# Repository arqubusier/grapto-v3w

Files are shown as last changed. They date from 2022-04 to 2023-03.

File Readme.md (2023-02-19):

# Prerequisites

## CAD Development

- Install Freecad
- Install KiCad
- Install Freecad KiCad StepUp plugin.
- install ergogen https://docs.ergogen.xyz/ (see below)
- Install https://github.com/perigoso/keyswitch-kicad-library.
  - Use the "Plugin and Content Manager" program of Kicad.
  - add the library path for Switch_Keyboard_Kailh 
  - Add value of the Kicad variable "KICAD6_3DMODEL_DIR" to secondary 3D folder location in KiCad StepUp
- Download the usb connector 3d model from https://www.molex.com/molex/part/partModels.jsp?&prodLevel=part&partNo=2169900001&channel=products
  to <repo>/grapto-v3w-pcb/216990-0001_stp/
  
### ergogen

$ npm i ergogen
installing globally causes permission errors depending on environment

You need to hack the footprints in gen_src/footprints into your local install of ergogen.

run ergogen (-d flag ouputs svg in addition to svg)

$ cd gen_src
$ ergogen -d config.yaml

Then copy kicad pcbs into the respective kicad project

## FW Development

  # src
  git clone git@github.com:arqubusier/zmk.git

  # packages
  sudo pacman -S git \
    autoconf \
    automake \
    ccache \
    dfu-util \
    libtool \
    make \
    gcc \
    ninja \
    cmake \

  pip install --user west

  # toolchains
  export ZSDK_VERSION=0.13.2
wget -q "https://github.com/zephyrproject-rtos/sdk-ng/releases/download/v${ZSDK_VERSION}/zephyr-toolchain-arm-${ZSDK_VERSION}-linux-x86_64-setup.run" && \
    sh "zephyr-toolchain-arm-${ZSDK_VERSION}-linux-x86_64-setup.run" --quiet -- -d ~/.local/zephyr-sdk-${ZSDK_VERSION} && \
    rm "zephyr-toolchain-arm-${ZSDK_VERSION}-linux-x86_64-setup.run"

  # west setup
  cd <zmk-repo>
  west init -l app/
  west update
  west zephyr-export
  pip install --user -r zephyr/scripts/requirements-base.txt

  yay -S nrf5x-command-line-tools
# FW Development

## Flashing

cd <zmk-repo>
cd app
west flash 
cd 
# FW Development

## Building

west build -p -b grapto_v3w

## Flashing

west flash

# Usage

## Pair on Arch Linux

Set report mode characteristic to report

$ sudo bluetoothctl
menu scan
clean
transport le
back
scan on
connect E9:9E:30:E3:E4:5B

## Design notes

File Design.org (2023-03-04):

* Soc

** nrf51xx
obsolete

** nrf52xx

https://infocenter.nordicsemi.com/index.jsp?topic=%2Fstruct_nrf52%2Fstruct%2Fnrf52.html

** Devboard

PCA10040 is an identifier for the devboard
*** Toolchain

*** Programmer

Segger jlink recommended

edu mini version ca 200 kr

Can use nrf52-dk to program external soc 300-400kr.
But do not need to buy separate devboard.

could use keyboard as devboard

**  bl653
** ACN52840
https://www.mouser.se/datasheet/2/871/aconno_02052021_ACN52840-2005184.pdf

*** External seconds oscillator reduces current

why?
https://github.com/joric/nrfmicro/wiki/Components#crystal
*** System design
VDD
VBUS
GND
USBP
USBN
swdio to header
swdclk to header
swo to header
keymatrix 5 row, 6 col
Bootloader config pin
Status led
reset button
FASTCHG enable
( built in 32.768 kHz XTAL (20-30 ppm) )

* BLE
** GAP
Generic access profile - how to access link layer

*** Advertisment

- Advertisement packets sent periodically

To save battery while feeling responsive, the device can start with a short
interval and decrease if there is no connection.

**** Advertisement properties
- Connectable
- scannable
- directed

**** Advertisement types

| Packet           | Connectable | Scannable | Directed | Example device                                               |
|------------------+-------------+-----------+----------+--------------------------------------------------------------|
| ADV_IND          | yes         | yes       | yes      |                      |
| ADV_DIRECT_IND   | yes         | no        | yes      | smart watch, keyboard, send to specific known central        |
| ADV_NON_CONN_IND | no          | no        | no       |                                                              |
| ADV_SCAN_ID      | no          | yes       | no       | simple sensor, use central can use send request to read data |
|                  |             |           |          |                                                              |

*** Scanning

Scanning is done periodically with a certain
- interval
- duration

Passive scanning

Active scanning

*** Connection

** GAP Roles
Keyboard will have the Peripheral role.

PC is the central?

peripheral does advertising

*** Connection

- Peripheral can only be connected to one central a time

  1. peripheral advertises
  2. Central responds on advertising channel
  3. Connection is formed

** GATT
access to data layer

Hierarchical table

Table of:
- Profile
  - Services
    - characteristics (single data point)

Peripheral is a GATT server, owns the table

*** Characteristics

Operations:
- command
- request
  - response
- notification
...

* PCB
** Rev 2
*** Testpoints
testpoints on critical mcu pin's to determine if reflow is good
- all vccs
- grounds
*** Status led
*** reset button
*** bootloader config pin
*** new power muxing
* Battery
** CR20xx
c == "lithium", r == "round", NNNN = diameter and height: 2032 means 20 mm high and 3.2 mm tall

cr2032
3 V 235 mAh

cr2025

thinner than cr2032 but smaller capacity 170 mAh.

** Battery holder

cannot find a "midmount battery holder"

Create own battery clips.

** LiPo
*** Posthuman Battery Store 303450
https://www.aliexpress.com/item/4001059965613.html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
Brand Name: ANLB
Type: Li-polymer
Set Type: Batteries Only
Model Number: 303450
Origin: Mainland China
Nominal Capacity: 600mAh
Bundle: Bundle 1
Certification: CE
Size: 50*34*3.0mm
Replacement Battery: Yes
Battery Number: 1pcs-2PCS
Charging Voltage: 3.7~4.2V

*** How far to discharge

Unclear, no datasheet on battey

3-3.6 V
https://lygte-info.dk/info/BatteryLowVoltage%20UK.html

* Power managament
https://circuitdigest.com/article/what-is-ldo-low-dropout-voltage-regulator-and-its-significance-in-battery-operated-devices

transient repsonse, rf sending
dropout voltage
** Detect and turn off at low battery

Use voltage divider and adc of controller, compare battery with voltage
divider. if adc is to low go into deep sleep. Wake up with reset button.

Use voltage regulator at 3.0V. Go to deep sleep when when at 3.0v.

*** Chip based soloution

https://electronics.stackexchange.com/questions/174781/low-battery-detection
https://www.mouser.se/datasheet/2/115/DIOD_S_A0002900337_1-2541999.pdf

MIC803 4.5 uA
MIC803-30D4VC3 vcc 3.3v vth 3
MIC803-29D4VC3 vcc 3.3 vth 2.93
https://www.mouser.se/datasheet/2/115/DIOD_S_A0002900337_1-2541999.pdf 

https://www.mouser.se/ProductDetail/621-AP9211SA-AN-HAC7
Has cutoff at 3.2, can be placed inline with battery

** Power profile
https://devzone.nordicsemi.com/power/w/opp/2/online-power-profiler-for-bluetooth-le

Dadv = 1/24
Dactive = 4/24
Dsleep = 19/24

Iavg = Dadv*Iadv+Dsleep*Isleep+DActive*Iactive = 1/24*100+19/24*30+4/24*700 uA =
150 uA

During advertising (not bonded) for rev1. But I am not able to pair. Also could not
cleanly cut trace so there is still 1M resistance in parallell with Am meter. So
values might be marginally larger. When not transmitting the average current is 2uA.

For 1 period, 100ms, average current ca 100us. Nrf power profiler shows 93 us so
not too far off.


** Keyboard scenarios
https://devzone.nordicsemi.com/power/w/opp/2/online-power-profiler-for-bluetooth-le

*** Not connected/Paired
50 ms interval
*** Reconnection (ADV_DIRECT_IND)

Read more here
file:///home/herman/Downloads/HOGP_SPEC_V10.pdf
20 h/day
{
  "chip": "2",
  "voltage": "3",
  "dcdc": "on",
  "lf_clock": "lfxo",
  "radio_tx": "0",
  "ble_type": "adv",
  "ble_int": "500",
  "tx_size": "0"
}
not sure if these settings are correct but this gives 21 uA

Configure long connection interval, but trigger reconnection/reduce interval
when pressing a button.

*** Connected, sending keypresses
1-4 hours at a time, a few times during the day.

go to reconnection mode after 20 min.

{
  "chip": "2",
  "voltage": "3",
  "dcdc": "on",
  "lf_clock": "lfxo",
  "radio_tx": "0",
  "ble_type": "con",
  "ble_int": "7.5",
  "tx_size": "6",
  "rx_size": "0",
  "phy": "1mbps",
  "slave_latency": "0",
  "central_ppm": "20",
  "peripheral_ppm": "20"
}

650uA

** Which Regulator type?

Optimize for reconnection mode 21uA, round up to 50uA

** LDO
https://www.eevblog.com/forum/projects/choosing-an-appropriate-ldo-for-low-power-device/
https://electronics.stackexchange.com/questions/275605/choosing-the-right-power-regulator-for-battery-powered-designs
https://devzone.nordicsemi.com/f/nordic-q-a/75124/is-this-robust-nrf52840-1-8v-low-power-mode-driving-rgb-led-from-3-3v

Is it better to use ldo than switchmode

Power approximation for LDO PD = (VIN – VOUT) × IOUT 
for battery (4.2-3.0)*I = 0.9*I when fully charged
nominally (3.7-3.0)*I = 0.5*I

for 50uA, PD = 25uW, n=.
P = 150uA*3V = 450 uW
for 150uA, PD = 75uW, n=450/(75+450)=0.85

lower quiescent current than spms.

fewer passives, smaller board space

THINK ABOUT THE DROPOUT VOLTAGE

transient response

*** TPS783xx
https://jlcpcb.com/partdetail/TexasInstruments-TPS78330DDCR/C118221

Iq 0.5uA

** Switchmode regulators

power approximation VIN = VOUT/Efficienccy = VOUT/0.9
Vregulator = Vout*(1/efficiency - 1) = Vout*(1/0.9 - 1) = Vout*0.11

for 50uA, 3.7V: VIN = 50*3.7*0.11 uW = 20uW

https://jlcpcb.com/partdetail/TexasInstruments-TPS63051RMWR/C139412
https://jlcpcb.com/partdetail/TexasInstruments-TPS63001DRCR/C28060

*** TPS62822
In stock at jlcpcb
https://jlcpcb.com/partdetail/TexasInstruments-TPS62822DLCR/C473385

see table on page 10
recommended output filter 0.47uH 22uF

r3, (PG) when not used can be left floating

*** TPS54331DR
To low minimum
input volgage
*** TPS6226x
For 1 cell lion batteries

small inductor 2.2 uH required
https://www.ti.com/cn/lit/ds/symlink/tps62260.pdf?ts=1677701886702&ref_url=https%253A%252F%252Fjlcpcb.com%252F

18 uA Iq
Rdson 150mOhm

*** TPS6242x
https://www.ti.com/cn/lit/ds/symlink/tps62420.pdf?ts=1677701846178&ref_url=https%253A%252F%252Fjlcpcb.com%252F

*** TPS6305x
** Battery disconnect switch (w7)
All smt slide switches I can find have I_max < 500 mA.
 - Use switch to turn off transistor that disconnects battery.
** Battery USB power muxing
*** None
- How is resistance of battery compared to mcu?
  will the battery "steal" all current?
  *Don't think this is an issue*
- Charging management is affected
  - More current will pass through the charger
  - Changing of states (CC, CV, etc.) might be negatively affected.
- System load will share current with battery from charger,
  charge current will be smaller. It may also vary due to system load.
- Charger turns off when charge current drops below threshlod. System load
  may cause charger to stay on when battery is 100% could lead to overcharge.
*** charger with power path
**** MCP738x
https://www.mouser.se/datasheet/2/268/20001984g-846362.pdf
- Not sure if battery in parallel with system ok.
**** BQ24073 WINNER!
https://www.mouser.se/ProductDetail/Texas-Instruments/BQ24073RGTR?qs=ZV%2Fxhq4oszqX%2F3rMt%2FwIsw%3D%3D
or BQ24072
- 1.5 A charge (wall adapter)
- input overvoltage
- Reverse current protection
- output short-circuit protection
- thermal protection
- reverse current protection
- inrush limit
- safety timers

***** Charging

- charge rate
- battery charge voltage 4.2, BQ24072, BQ24073, BQ24075, BQ24075
- charge rate I_charge set by ISET
- CHG on (low), means charging
- Flashing CHG, means error during charge
***** Current limit
During poweron, input current limit is first set to 100mA.
En1, EN2, R_ilim
***** Power management
- EN1 == EN2 == hi, in power ON, standby mode, battery power, input power disconnected
- Bq24073, out is regulated when IN present
  - DPPM Mode: if Vout starts dropping, charing current will be reduced
  - Battery Supplement mode: if charging current drops to zero and system load
    is greater than input current limit, OUT will not be regulated, but the
    battery will be connected directly to out
  - When no input source is present, battery is directly connected to out and no
    regulation is performed.
- Input current is current limited compliant with usb
- Input cap less than 10uF to limit inrush current
- Input current level controlled either by EN1/EN2 or resistor between ILIM an VSS.
***** Testing
Disconnect battery, connect charger.
1. OUT == ???

Connect battery, connect charger.
1. Input current is less than or equal to 100 mA.
2. CHG is on, PGOOD is on
3. Heat of ic is ok.
5. when charging is done CHG turns off
6. battery voltage is 4.2 V
***** Charging
max(current limit, I_chg)

I_chg = K_iset / R_iset

TD pin should be floating or low to enable charge termination.

TMR controls charge timers. Leave floating to use default values.

TS, battery pack temperature monitoring, connect 10 kOhm resistor from TS to VSS
to enable charging without temperature monitoring.

ILIM  Leaving ILIM unconnected disables all charging.

***** Thermal
Connect thermal pad to vss

thermal performance 
θ_JA = (T_J - T) / P 

P = [V(IN) – V(OUT)] × [I(OUT) + I(BAT)] + [V(OUT) – V(BAT)] × I(BAT)

eg.

P = [5.5 - 4.4]*0.500+[4.4-3.4]*0.500 W = 1.05 W

Test charging at 400 mA and see if battery or charger does not get too warm.

***** System design
BAT
!CE Connect to logic low to enable charging
!CHG Connect to led with resistor, indicates charging, flashes if error during charging
EN1 connect to logic low
EN2 connect to mcu, logic 1 FASTCHG enables 500mA current limit
ILIM Connect to resistor RILIM to ground = KILIM / RILIM
  RILIM = KILIM/ILIM ~ 1525/0.5 = 3.05 kOhm, Use 3.3 kOhm for smaller current
  limit
IN connect to VBUS, add cap less than 10uF to limit inrush current
ISET connecto to resistor RISET to grount = KISET/RISET
  RISET = KISET/ISET ~ 890/0.4 Ohm = 2.225 KOhm, use 2.2 kOhm resistor
ITERM leave unconnected for default termination current
OUT connect to system, 4.4 V or battery voltage
!PGOOD connect to led with resistor, indicates good power source
SYSOFF Connect Sysoff to logic low to enable battery output
TD Connect to ground to enable charger termination
thermal pad connect to ground
TMR leave unconnected for default timer values
TS Connect 10 KOhm resistor to ground (enable charging without batt temp sensor)
VSS connect to ground.

**** BQ25616
https://www.mouser.se/ProductDetail/Texas-Instruments/BQ25616JRTWT?qs=GBLSl2Akiruk9chMI62zkQ%3D%3D
- 9.5 uA standby
- High input voltage
- powerpath
- usb otg
- switched
- 3 A charge
**** BQ24081
https://www.mouser.se/ProductDetail/Texas-Instruments/BQ24081DRCTG4?qs=sjHPNSjTyn1tPpHjbn571g%3D%3D
- Batter in parallel with system
- Safety timer
- 1 A charge
**** BQ25606
https://www.mouser.se/ProductDetail/Texas-Instruments/BQ25606RGET?qs=5aG0NVq1C4yFkgOQCbyUyg%3D%3D
- powerpath
- usb otg
- switched
- 3 A charge
- 58 uA standby current
- inrush current limit
**** BQ24195
https://datasheet.lcsc.com/lcsc/1912112237_Texas-Instruments-BQ24195LRGER_C417486.pdf

*** diode oring

https://www.mouser.se/datasheet/2/916/PMEG3020CEP-1599881.pdf

If=1A,Tj=25 -> R<360mOhm

use beefier schottky on the usb side

*** IC powermux
TPS2110, TPS2111
https://www.ti.com/lit/ds/symlink/tps2110.pdf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
Around 100mOhm Rds(on)

+ more expensive than schottky
- lower on resistance
+ surge protection (could be useful for usb but might not be usable)
+ current limit -> no fuse for mcu needed
+ added IC dependency on component

*** Custom design

+ Cheap components?
+ lower on resistance than Schottky?
- complexity
- space
- Don't know how to limit cross-conductance

* Debug connector

Acn has a 6-pin connector. Pinout?????

* ESD
* Case

** w7

** w6

How much should the keyboard be raised? 7.5 mm at the end.

*** slanted case
- breaks w1

*** flip up feet
- breaks w2
- How to prevent slipping?

*** Tall bumpons at the back, sholt bumpons at the front

* Key pins

| logical name | bl653 pin | nrf52833 pin |
|--------------+-----------+--------------|
| col0         |        37 |            7 |
| col1         |        35 |            6 |
| col2         |        29 |            8 |
| col3         |        27 |           11 |
| col4         |        21 |           16 |
| col5         |        13 |           20 |
| row0         |        46 |           28 |
| row1         |        42 |            0 |
| row2         |        41 |            1 |
| row3         |        39 |            5 |
| row4         |         7 |           32 |

* flash map

- arduino boot loader
- soft device? NO zephyr uses it's own bluettooth stack
- application code 

* Troubleshooting
** Troubleshoot ZMK
*** Flash simple example
https://docs.zephyrproject.org/2.7.0/samples/basic/blinky/README.html
**** on nrf52dk in zephyr tree
https://docs.zephyrproject.org/latest/develop/getting_started/index.html

cd ~/bin
wget https://github.com/zephyrproject-rtos/sdk-ng/releases/download/v0.14.2/zephyr-sdk-0.14.2_linux-x86_64.tar.gz
wget -O - https://github.com/zephyrproject-rtos/sdk-ng/releases/download/v0.14.2/sha256.sum |shasum --check --ignore-missing
tar -xzvf zephyr-sdk-0.14.2_linux-x86_64.tar.gz
cd ~/src
mkdir zephyrproject2
cd zephyrproject2
west init
west update
west zephyr-export
cd ~/src/zephyrproject2/zephyr
pip install --user scripts/requirements.txt

***** blinky
cd ~/src/zephyrproject2/zephyr
west build -p auto -b nrf52dk_nrf52832 samples/basic/blinky
west flash

WORKS led is blinking

***** ble
west build -p auto -b nrf52dk_nrf52832 samples/bluetooth/peripheral_hids
west flash

Device shows up as Test HoG mouse in nrfConnect

**** on nrf52dk in zmk tree
**** on grapto in zephyr tree
works blinky and ble peripheral example works!

Added grapto_v3w board to zephyr 
https://github.com/arqubusier/zephyr/tree/grapto_v3w/boards/arm/grapto_v3w

**** on grapto in zmk tree

*** Try flashing zmk onto nrf52dk

soc is nrf52832_qfaa

not working
**** when building
FAILED: zephyr/zmk.elf zephyr/zmk.map zephyr/zmk.hex zephyr/zmk.bin zephyr/zmk.uf2 zephyr/zmk.lst zephyr/zmk.stat /home/herman/src/zmk/app/build/zephyr/zmk.map /home/herman/src/zmk/app/build/zephyr/zmk.hex /home/herman/src/zmk/app/build/zephyr/zmk.bin /home/herman/src/zmk/app/build/zephyr/zmk.uf2 /home/herman/src/zmk/app/build/zephyr/zmk.lst /home/herman/src/zmk/app/build/zephyr/zmk.stat 
: && ccache /home/herman/.local/zephyr-sdk-0.13.2/arm-zephyr-eabi/bin/arm-zephyr-eabi-gcc   zephyr/CMakeFiles/zephyr_final.dir/misc/empty_file.c.obj zephyr/CMakeFiles/zephyr_final.dir/dev_handles.c.obj zephyr/CMakeFiles/zephyr_final.dir/isr_tables.c.obj -o zephyr/zmk.elf  zephyr/CMakeFiles/offsets.dir/./arch/arm/core/offsets/offsets.c.obj  -fuse-ld=bfd  -Wl,-T  zephyr/linker.cmd  -Wl,-Map=/home/herman/src/zmk/app/build/zephyr/zephyr_final.map  -Wl,--whole-archive  app/libapp.a  zephyr/libzephyr.a  zephyr/arch/common/libarch__common.a  zephyr/arch/arch/arm/core/aarch32/libarch__arm__core__aarch32.a  zephyr/arch/arch/arm/core/aarch32/cortex_m/libarch__arm__core__aarch32__cortex_m.a  zephyr/arch/arch/arm/core/aarch32/mpu/libarch__arm__core__aarch32__mpu.a  zephyr/lib/libc/minimal/liblib__libc__minimal.a  zephyr/lib/posix/liblib__posix.a  zephyr/soc/arm/common/cortex_m/libsoc__arm__common__cortex_m.a  zephyr/soc/arm/nordic_nrf/nrf52/libsoc__arm__nordic_nrf__nrf52.a  zephyr/subsys/bluetooth/common/libsubsys__bluetooth__common.a  zephyr/subsys/bluetooth/host/libsubsys__bluetooth__host.a  zephyr/subsys/bluetooth/controller/libsubsys__bluetooth__controller.a  zephyr/subsys/net/libsubsys__net.a  zephyr/subsys/random/libsubsys__random.a  zephyr/drivers/adc/libdrivers__adc.a  zephyr/drivers/clock_control/libdrivers__clock_control.a  zephyr/drivers/gpio/libdrivers__gpio.a  zephyr/drivers/flash/libdrivers__flash.a  zephyr/drivers/entropy/libdrivers__entropy.a  zephyr/drivers/timer/libdrivers__timer.a  modules/hal_nordic/nrfx/libmodules__hal_nordic__nrfx.a  modules/drivers/kscan/libzmk__drivers__kscan.a  modules/drivers/sensor/battery/lib..__app__drivers__sensor__battery.a  -Wl,--no-whole-archive  zephyr/kernel/libkernel.a  -L"/home/herman/.local/zephyr-sdk-0.13.2/arm-zephyr-eabi/bin/../lib/gcc/arm-zephyr-eabi/10.3.0/thumb/v7e-m/nofp"  -L/home/herman/src/zmk/app/build/zephyr  -lgcc  -Wl,--print-memory-usage  zephyr/arch/common/libisr_tables.a  -no-pie  -mcpu=cortex-m4  -mthumb  -mabi=aapcs  -mfp16-format=ieee  -Wl,--gc-sections  -Wl,--build-id=none  -Wl,--sort-common=descending  -Wl,--sort-section=alignment  -Wl,-u,_OffsetAbsSyms  -Wl,-u,_ConfigAbsSyms  -nostdlib  -static  -Wl,-X  -Wl,-N  -Wl,--orphan-handling=warn && cd /home/herman/src/zmk/app/build/zephyr && /usr/bin/cmake -E rename zephyr_final.map zmk.map && /home/herman/.local/zephyr-sdk-0.13.2/arm-zephyr-eabi/bin/arm-zephyr-eabi-objcopy --gap-fill 0xff --output-target=ihex --remove-section=.comment --remove-section=COMMON --remove-section=.eh_frame zmk.elf zmk.hex && /home/herman/.local/zephyr-sdk-0.13.2/arm-zephyr-eabi/bin/arm-zephyr-eabi-objcopy --gap-fill 0xff --output-target=binary --remove-section=.comment --remove-section=COMMON --remove-section=.eh_frame zmk.elf zmk.bin && /usr/bin/python3.10 /home/herman/src/zmk/zephyr/scripts/uf2conv.py -c -f -b 0x0 -o zmk.uf2 zmk.bin && /home/herman/.local/zephyr-sdk-0.13.2/arm-zephyr-eabi/bin/arm-zephyr-eabi-objdump -d -S zmk.elf > zmk.lst && /home/herman/.local/zephyr-sdk-0.13.2/arm-zephyr-eabi/bin/arm-zephyr-eabi-readelf -e zmk.elf > zmk.stat
Memory region         Used Size  Region Size  %age Used
           FLASH:      146128 B       448 KB     31.85%
            SRAM:       42430 B        64 KB     64.74%
        IDT_LIST:          0 GB         2 KB      0.00%
usage: uf2conv.py [-h] [-b BASE] [-o FILE] [-d DEVICE_PATH] [-l] [-c] [-D]
                  [-f FAMILY] [-C]
                  [INPUT]
uf2conv.py: error: argument -f/--family: expected one argument
ninja: build stopped: subcommand failed.
FATAL ERROR: command exited with status 1: /usr/bin/cmake --build /home/herman/src/zmk/app/build
?1 ~/src/zmk/app % 

**** only build hex -> skip uf2conv.py
commented-out this line

#CONFIG_BUILD_OUTPUT_UF2=y

now I can build and flash

*** Start from working bl653 board in zmk

*** does not enter zmk's main

does not enter zmk's main.c
ends up in cpu_idle.s after z_arm_configure_static_mpu_regions

**** Need storage partition for bluetooth

**** Increase stack size

Added to Kconfig.defconfig

config MAIN_STACK_SIZE
    int
    default 4096

config SYSTEM_WORKQUEUE_STACK_SIZE
    int
    default 4096

config ISR_STACK_SIZE
    int
    default 4096

**** Check partition page alignment
page size is 4096

0x60000/4096 == 384 -> OK

total size is 512 KibiByte (I Assume, it sayes 512 KBytes on nrf homepage)
0x80000 == 524288
524288/1024 == 512 -> OK

**** Mpu config setting

Troubleshooting
***************

MPU fault while using NVS, or ``-ETIMEDOUT`` error returned
   NVS can use the internal flash of the SoC.  While the MPU is enabled,
   the flash driver requires MPU RWX access to flash memory, configured
   using :kconfig:`CONFIG_MPU_ALLOW_FLASH_WRITE`.  If this option is
   disabled, the NVS application will get an MPU fault if it references
   the internal SoC flash and it's the only thread running.  In a
   multi-threaded application, another thread might intercept the fault
   and the NVS API will return an ``-ETIMEDOUT`` error.

**** MPU error

void arm_core_mpu_configure_static_mpu_regions(const struct z_arm_mpu_partition
  static_regions[], const uint8_t regions_num,
  const uint32_t background_area_start, const uint32_t background_area_end)
{
  if (mpu_configure_static_mpu_regions(static_regions, regions_num,
                 background_area_start, background_area_end) == -EINVAL) {

    __ASSERT(0, "Configuring %u static MPU regions failed\n",
      regions_num);
  }
}

Hits assert!!!

**** partition@XXXXXXXX was wrong
&flash0 {
	/*
	 * Using no boot loader for now.
	 */
	partitions {
		compatible = "fixed-partitions";
		#address-cells = <1>;
		#size-cells = <1>;

		code_partition: partition@0 {
			label = "code_partition";
			reg = <0x00000000 0x60000>;
		};

		/*
		 * Storage partition will be used by FCB/LittleFS/NVS
		 * if enabled.
		 */
		storage_partition: partition@60000 { // PROBLEM WAS here
			label = "storage";
			reg = <0x00060000 0x00020000>;
		};
	};
};

*** hard fault
hard fault before main

static int zmk_usb_init(const struct device *_arg) {
zmk_endpoints_init(
static int zmk_usb_hid_init(const struct device *_arg)

zmk_battery_init

Skips main here
static void bg_thread_main(void *unused1, void *unused2, void *unused3)

** Right half not working

error when trying to program

ERROR: Unable to connect to a debugger.
ERROR: JLinkARM DLL reported an error. Try again. If error condition
ERROR: persists, run the same command again with argument --log, contact Nordic
ERROR: Semiconductor and provide the generated log.log file to them.
NOTE: For additional output, try running again with logging enabled (--log).
NOTE: Any generated log error messages will be displayed.
FATAL ERROR: command exited with status 33: nrfjprog --program /home/herman/src/zmk/app/build/zephyr/zmk.hex --sectoranduicrerase -f NRF52 --snr 682314080

*** Is mcu soldered on correctly?
Resolder

short on swdio to gnd!!!

*** Check swd connections on pcb
pwr 3v3 ok
*** monitor swd pins
*** Try program with usb power only
***

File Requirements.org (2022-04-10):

* Requirements
The project will go on indefinitely until these the system meets these.
| Id   | Description                                                                  |
|------+------------------------------------------------------------------------------|
| r1   | the keyboard is wireless                                                     |
| r2   | the keyboard is battery powered                                              |
| r3   | the keyboard has on-board charging                                           |
| r4.1 | the pcb protects the battery from overcharging                               |
| r4.2 | the pcb protects the battery from overdischarging                            |
| r4.3 | the pcb protects the battery from overcurrents                               |
| r4.4 | the pcb charges the battery in a manner that is safe given the its chemistry |
| r5   | the battery is charged using a usb cable                                     |
| r6   | the keyboard is split                                                        |
|      |                                                                              |

* Want to haves
I want the system to have these features.

| Id   | Description                                                                                |
|------+--------------------------------------------------------------------------------------------|
| w1   | The case is less than or equal to 6 mm in height                                           |
| w2   | The case only has a single seam on the bottom separating the top part from the bottom part |
| w3   | The keyboard can be operated with the usb plugged in and the battery unplugged             |
| w4   | Both halves can be charged using a single cable going to the usb charger                   |
| w5   | The keyboard can be operated with usb plugged in and the battery  plugged in               |
| w6   | the keyboard can be raised                                                                 |
| w6.1 | the keyboard raising mechanism does not need external parts                                |
| w7   | the battery can be disconnected using a switch                                             |
|      |                                                                                            |

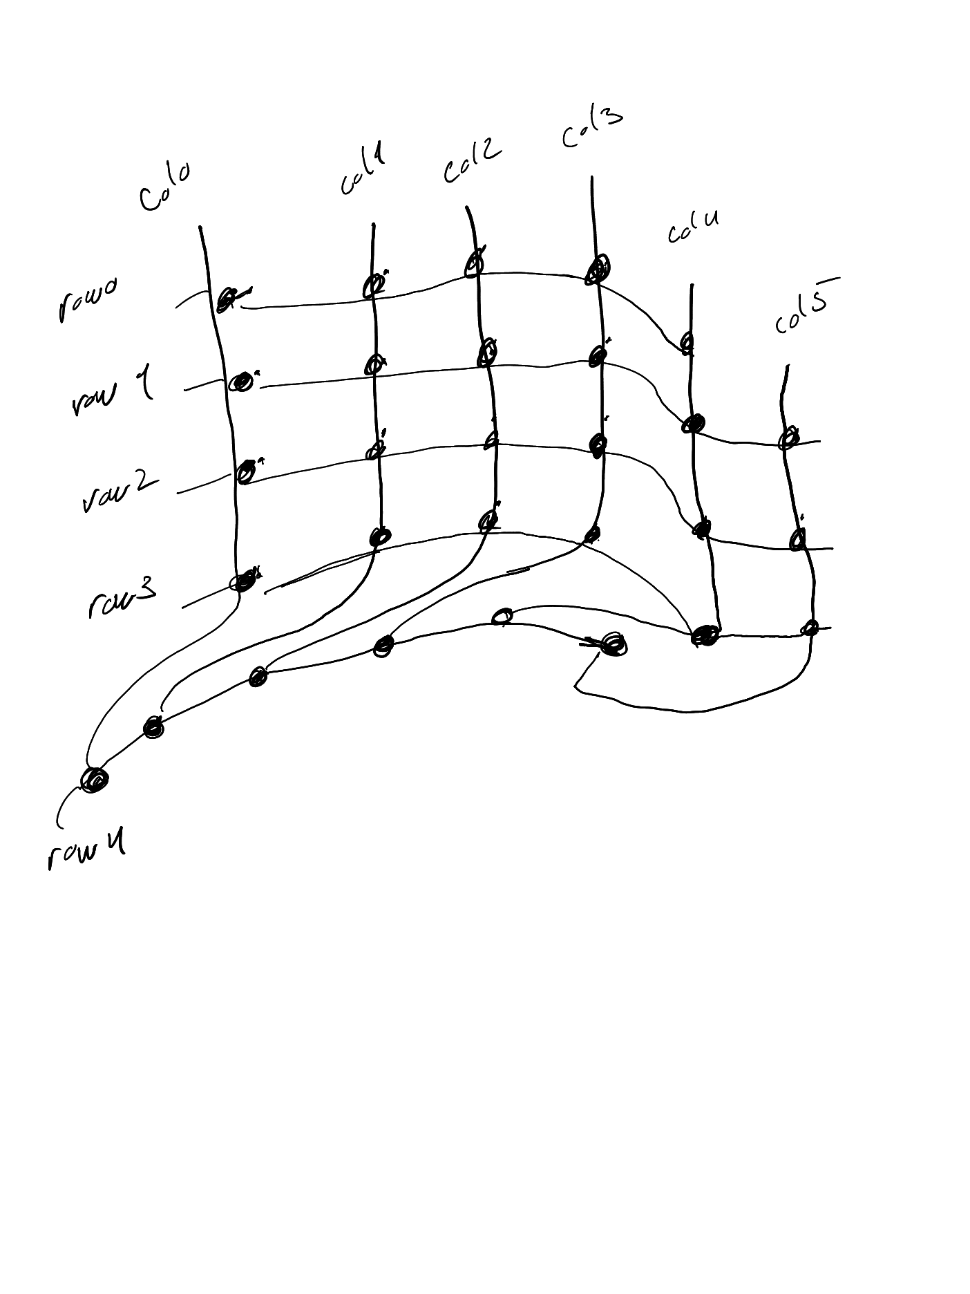
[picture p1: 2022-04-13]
grapto-v3w-shared/matrix.png

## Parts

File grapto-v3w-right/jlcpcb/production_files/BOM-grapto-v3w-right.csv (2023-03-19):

Comment | Designator | Footprint | LCSC
1M2 | R19 | R_0603_1608Metric_Pad0.98x0.95mm_HandSolder | C137774
.1u | C5 | C_0603_1608Metric_Pad1.08x0.95mm_HandSolder | C14663
1u | C1 | C_0603_1608Metric_Pad1.08x0.95mm_HandSolder | C15849
0.01m | R13,R14,R2 | R_0603_1608Metric_Pad0.98x0.95mm_HandSolder | C21189
3.3K | R7 | R_0603_1608Metric_Pad0.98x0.95mm_HandSolder | C22978
3M | R30 | R_0603_1608Metric_Pad0.98x0.95mm_HandSolder | C23156
5.1k | R20,R23 | R_0603_1608Metric_Pad0.98x0.95mm_HandSolder | C23186
22 | R24,R25 | R_0603_1608Metric_Pad0.98x0.95mm_HandSolder | C23345
100k | R9 | R_0603_1608Metric_Pad0.98x0.95mm_HandSolder | C25803
10K | R4 | R_0603_1608Metric_Pad0.98x0.95mm_HandSolder | C25804
453k | R5 | R_0603_1608Metric_Pad0.98x0.95mm_HandSolder | C273765
68 | R1 | R_0603_1608Metric_Pad0.98x0.95mm_HandSolder | C27592
LED_ARGB | D30,D31,D32 | 23-23B-R6GHBHC-A01-2A | C2827866
Polyfuse | F3,F4 | Fuse_0603_1608Metric_Pad1.05x0.95mm_HandSolder | C2844463
470n | L2 | MHCI05020-R47M-R8 | C285730
Conn_01x02_Female | J1 | JST_PH_S2B-PH-SM4-TB_1x02-1MP_P2.00mm_Horizontal | C295747
2.2K | R8 | R_0603_1608Metric_Pad0.98x0.95mm_HandSolder | C4190
TPS62822DLC | U2 | Texas_VSON-HR-8_1.5x2mm_P0.5mm | C473385
SW_SPDT | SW31 | SW_SK-3296S-01-L2 | C500051
 | S59,S60,S61,S62,S63,S64,S65,S66,S67,S68,S69,S70,S71,S72,S73,S74,S75,S76,S77,S78,S79,S80,S81,S82,S83,S84,S85,S86,S87 | PG1350 | C5333465
BQ24075RGT | U4 | VQFN-16-1EP_3x3mm_P0.5mm_EP1.6x1.6mm | C544783
22u | C10,C16,C17,C3,C4,C6,C7 | C_0603_1608Metric_Pad1.08x0.95mm_HandSolder | C59461
USBLC6-2SC6 | U3 | SOT-23-6 | C7519
 | D59,D60,D61,D62,D63,D64,D65,D66,D67,D68,D69,D70,D71,D72,D73,D74,D75,D76,D77,D78,D79,D80,D81,D82,D83,D84,D85,D86,D87 | ComboDiode | C81598
120p | C2 | C_0603_1608Metric_Pad1.08x0.95mm_HandSolder | C85974
~ | TP22 | TestPoint_THTPad_D2.0mm_Drill1.0mm
TestPoint | TP18 | TestPoint_THTPad_D2.0mm_Drill1.0mm
TestPoint | TP17 | TestPoint_THTPad_D2.0mm_Drill1.0mm
TestPoint | TP16 | TestPoint_THTPad_D2.0mm_Drill1.0mm
TestPoint | TP15 | TestPoint_THTPad_D2.0mm_Drill1.0mm
TestPoint | TP14 | TestPoint_THTPad_D2.0mm_Drill1.0mm
TestPoint | TP13 | TestPoint_THTPad_D2.0mm_Drill1.0mm
TestPoint | TP11 | TestPoint_THTPad_D2.0mm_Drill1.0mm
TestPoint | TP10 | TestPoint_THTPad_D2.0mm_Drill1.0mm
TestPoint | TP1 | TestPoint_THTPad_D2.0mm_Drill1.0mm
ACN52840 | U1 | ACN52840
USB_C_Receptacle_USB2.0 | J6 | USB_C_Receptacle_G-Switch_GT-USB-7004

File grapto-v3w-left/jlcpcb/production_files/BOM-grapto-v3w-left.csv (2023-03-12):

Comment | Designator | Footprint | LCSC
1M2 | R19 | R_0603_1608Metric_Pad0.98x0.95mm_HandSolder | C137774
1u | C1,C10,C16,C17,C3,C4,C6,C7 | C_0603_1608Metric_Pad1.08x0.95mm_HandSolder | C15849
0.01m | R13,R14,R2 | R_0603_1608Metric_Pad0.98x0.95mm_HandSolder | C21189
3.3K | R7 | R_0603_1608Metric_Pad0.98x0.95mm_HandSolder | C22978
3M | R30 | R_0603_1608Metric_Pad0.98x0.95mm_HandSolder | C23156
5.1k | R20,R23 | R_0603_1608Metric_Pad0.98x0.95mm_HandSolder | C23186
22 | R24,R25 | R_0603_1608Metric_Pad0.98x0.95mm_HandSolder | C23345
100k | R9 | R_0603_1608Metric_Pad0.98x0.95mm_HandSolder | C25803
10K | R4 | R_0603_1608Metric_Pad0.98x0.95mm_HandSolder | C25804
USB_C_Receptacle_USB2.0 | J6 | USB_C_Receptacle_G-Switch_GT-USB-7010ASV | C2686968
453k | R5 | R_0603_1608Metric_Pad0.98x0.95mm_HandSolder | C273765
.1u | C5 | C_0603_1608Metric_Pad1.08x0.95mm_HandSolder | C28233
LED_ARGB | D30,D31,D32 | 23-23B-R6GHBHC-A01-2A | C2827866
Polyfuse | F3,F4 | Fuse_0603_1608Metric_Pad1.05x0.95mm_HandSolder | C2844463
470n | L2 | MHCI05020-R47M-R8 | C285730
Conn_01x02_Female | J1 | JST_PH_S2B-PH-SM4-TB_1x02-1MP_P2.00mm_Horizontal | C295747
2.2K | R8 | R_0603_1608Metric_Pad0.98x0.95mm_HandSolder | C4190
62 | R1 | R_0603_1608Metric_Pad0.98x0.95mm_HandSolder | C4260
TPS62822DLC | U2 | Texas_VSON-HR-8_1.5x2mm_P0.5mm | C473385
SW_SPDT | SW31 | SW_SK-3296S-01-L2 | C500051
 | S1,S10,S100,S101,S102,S103,S104,S105,S106,S107,S108,S109,S11,S110,S111,S112,S113,S114,S115,S116,S12,S13,S14,S15,S16,S17,S18,S19,S2,S20,S21,S22,S23,S24,S25,S26,S27,S28,S29,S3,S4,S5,S6,S7,S8,S88,S89,S9,S90,S91,S92,S93,S94,S95,S96,S97,S98,S99 | PG1350 | C5333465
BQ24075RGT | U4 | VQFN-16-1EP_3x3mm_P0.5mm_EP1.6x1.6mm | C544783
USBLC6-2SC6 | U3 | SOT-23-6 | C7519
 | D100,D101,D102,D103,D104,D105,D106,D107,D108,D109,D110,D111,D112,D113,D114,D115,D116,D88,D89,D90,D91,D92,D93,D94,D95,D96,D97,D98,D99 | ComboDiode | C81598
120p | C2 | Fuse_0603_1608Metric_Pad1.05x0.95mm_HandSolder | C85974
ACN52840 | U1 | ACN52840
Conn_01x06_Male | J8 | PinHeader_1x06_P2.54mm_Vertical
~ | TP22 | PinHeader_1x01_P2.54mm_Vertical
TestPoint | TP18 | PinHeader_1x01_P2.54mm_Vertical
TestPoint | TP17 | PinHeader_1x01_P2.54mm_Vertical
TestPoint | TP16 | PinHeader_1x01_P2.54mm_Vertical
TestPoint | TP15 | PinHeader_1x01_P2.54mm_Vertical
TestPoint | TP14 | PinHeader_1x01_P2.54mm_Vertical
TestPoint | TP13 | PinHeader_1x01_P2.54mm_Vertical
TestPoint | TP11 | PinHeader_1x01_P2.54mm_Vertical
TestPoint | TP10 | PinHeader_1x01_P2.54mm_Vertical
TestPoint | TP1 | PinHeader_1x01_P2.54mm_Vertical

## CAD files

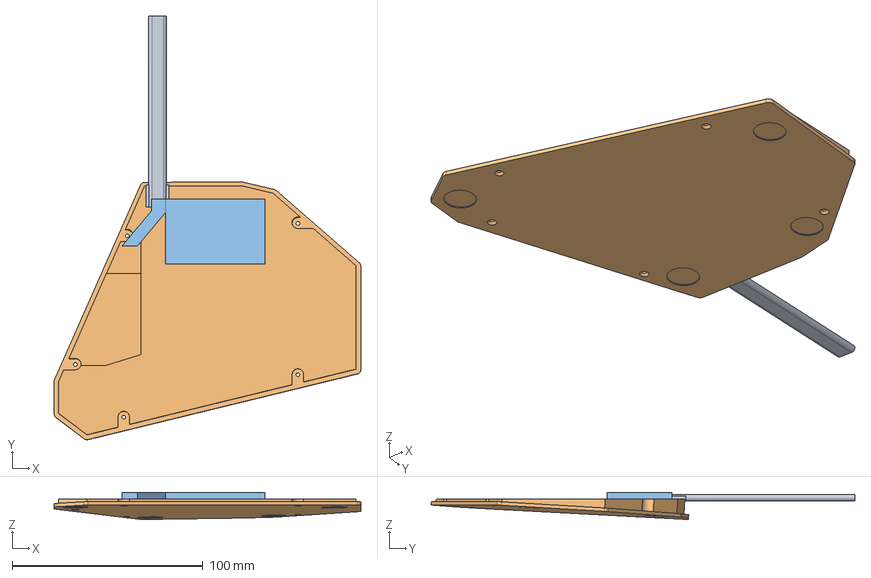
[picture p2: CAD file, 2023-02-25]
case/grapto-v3w-pcb-model.FCStd
161.0 x 222.2 x 14.2 mm
UsbHole
Bottom
BatteryHole

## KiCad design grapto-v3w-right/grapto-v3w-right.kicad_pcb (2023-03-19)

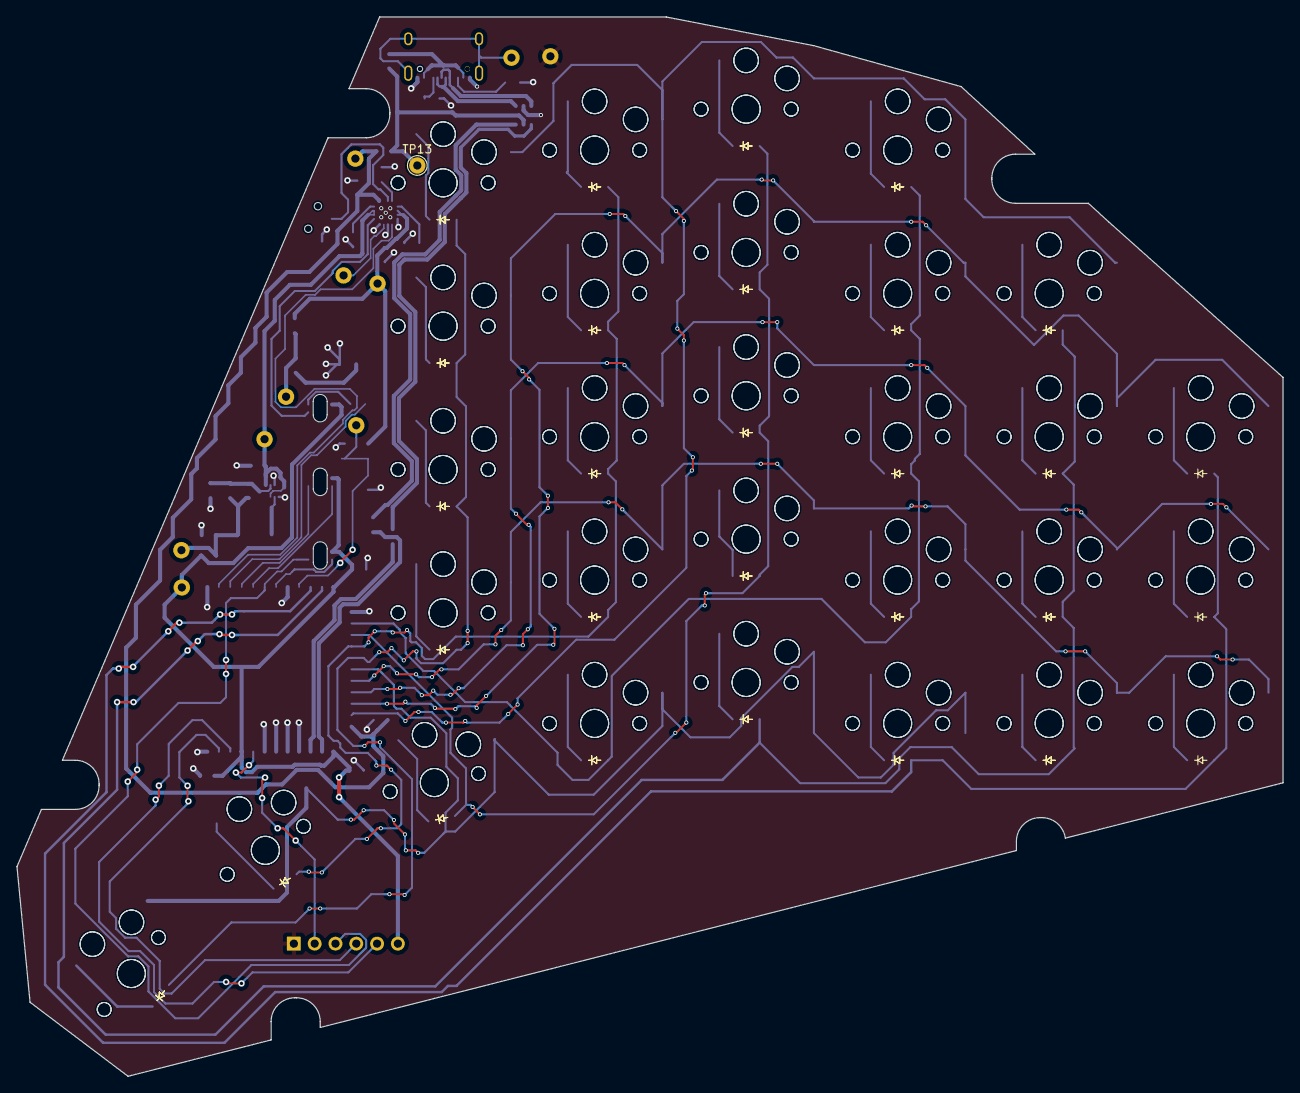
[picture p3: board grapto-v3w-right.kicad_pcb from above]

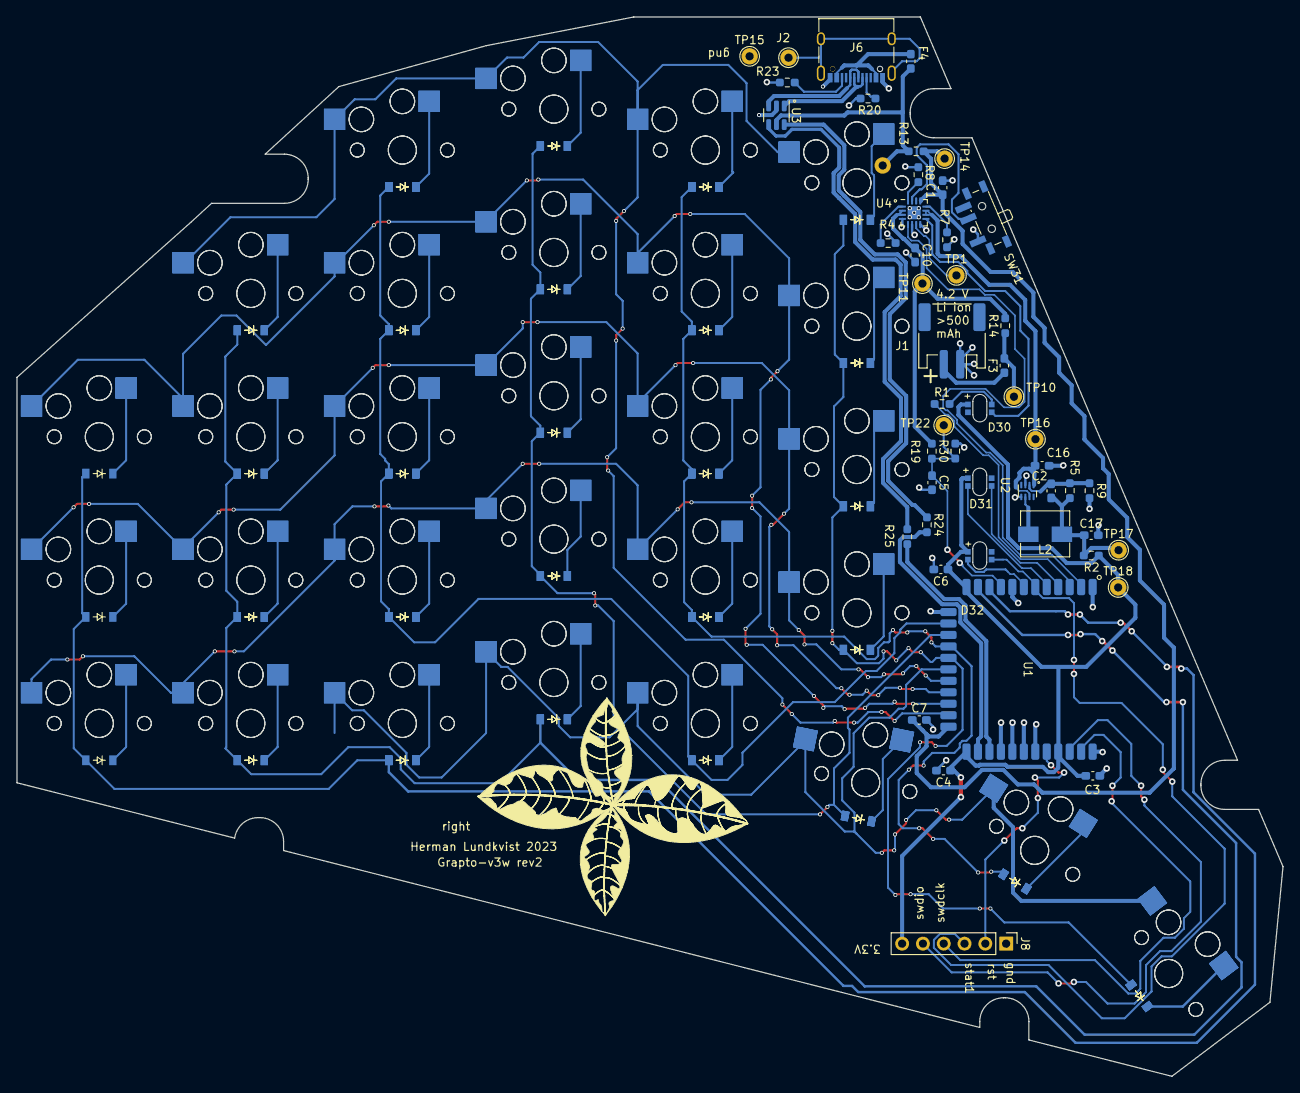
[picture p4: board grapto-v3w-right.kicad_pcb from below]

Board: 2 copper layers, 154.6 x 129.3 mm, 163 parts (49 on the bottom side), 78 nets.

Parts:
C1: 1u; C_0603_1608Metric_Pad1.08x0.95mm_HandSolder
C2: 120p; C_0603_1608Metric_Pad1.08x0.95mm_HandSolder
C3, C4, C6, C7, C10, C16, C17: 22u; C_0603_1608Metric_Pad1.08x0.95mm_HandSolder
C5: .1u; C_0603_1608Metric_Pad1.08x0.95mm_HandSolder
D30, D31, D32: LED_ARGB; 23-23B-R6GHBHC-A01-2A
D33, D34, D35, D36, D37, D38, D39, D40, D41, D42, D43, D44, D45, D46, D47, D48, D49, D50, D51, D52, D53, D54, D55, D56, D57, D58, D59, D60, D61, D62, D63, D64, D65, D66, D67, D68, D69, D70, D71, D72, D73, D74, D75, D76, D77, D78, D79, D80, D81, D82, D83, D84, D85, D86, D87: ComboDiode
F3, F4: Polyfuse; Fuse_0603_1608Metric_Pad1.05x0.95mm_HandSolder
J1: Conn_01x02_Female; JST_PH_S2B-PH-SM4-TB_1x02-1MP_P2.00mm_Horizontal
J2: Conn_01x01_Female; TestPoint_THTPad_D2.0mm_Drill1.0mm
J6: USB_C_Receptacle_USB2.0; USB_C_Receptacle_G-Switch_GT-USB-7004
J8: Conn_01x06_Male; PinHeader_1x06_P2.54mm_Vertical
L2: 470n; MHCI05020-R47M-R8
R1: 68; R_0603_1608Metric_Pad0.98x0.95mm_HandSolder
R2, R13, R14: 0.01m; R_0603_1608Metric_Pad0.98x0.95mm_HandSolder
R4: 10K; R_0603_1608Metric_Pad0.98x0.95mm_HandSolder
R5: 453k; R_0603_1608Metric_Pad0.98x0.95mm_HandSolder
R7: 3.3K; R_0603_1608Metric_Pad0.98x0.95mm_HandSolder
R8: 2.2K; R_0603_1608Metric_Pad0.98x0.95mm_HandSolder
R9: 100k; R_0603_1608Metric_Pad0.98x0.95mm_HandSolder
R19: 1M2; R_0603_1608Metric_Pad0.98x0.95mm_HandSolder
R20, R23: 5.1k; R_0603_1608Metric_Pad0.98x0.95mm_HandSolder
R24, R25: 22; R_0603_1608Metric_Pad0.98x0.95mm_HandSolder
R30: 3M; R_0603_1608Metric_Pad0.98x0.95mm_HandSolder
S30, S31, S32, S33, S34, S35, S36, S37, S38, S39, S40, S41, S42, S43, S44, S45, S46, S47, S48, S49, S50, S51, S52, S53, S54, S55, S56, S57, S58, S59, S60, S61, S62, S63, S64, S65, S66, S67, S68, S69, S70, S71, S72, S73, S74, S75, S76, S77, S78, S79, S80, S81, S82, S83, S84, S85, S86, S87: PG1350
SW31: SW_SPDT; SW_SK-3296S-01-L2
TP1, TP10, TP11, TP13, TP14, TP15, TP16, TP17, TP18: TestPoint; TestPoint_THTPad_D2.0mm_Drill1.0mm
TP22: TestPoint_THTPad_D2.0mm_Drill1.0mm
U1: ACN52840
U2: TPS62822DLC; Texas_VSON-HR-8_1.5x2mm_P0.5mm
U3: USBLC6-2SC6; SOT-23-6
U4: BQ24075RGT; VQFN-16-1EP_3x3mm_P0.5mm_EP1.6x1.6mm

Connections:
/controller/BatteryManagement/bat+: F3.1, J1.2
/controller/BatteryManagement/bat_fused: C10.1, R14.2, R19.1, TP11.1, U4.2 (BAT), U4.3 (BAT)
/controller/bat_lvl1: D31.3 (GK), U1.4 (P1.15)
/controller/bat_lvl2: D31.4 (BK), U1.5 (P0.02/AIN0)
/controller/chassi: J2.1, J6.S1 (SHIELD)
/controller/chg_led: D30.3 (GK), U4.9 (~CHG)
/controller/fast_chg: U1.2 (P1.10), U4.5 (EN2)
/controller/fast_chg_led: R1.1, U1.3 (P1.13)
/controller/low_batt: C5.1, R19.2, R30.1, TP22.1, U1.9 (P0.31/AIN7)
/controller/reset: J8.2, U1.31 (RST/SWO)
/controller/status1: D32.3 (GK), J8.3, U1.6 (P0.04/AIN1)
/controller/status2: D32.4 (BK), U1.7 (P0.28/AIN4)
/controller/swdclk: J8.4, U1.34 (SWDCLK)
/controller/swdio: J8.5, U1.33 (SWDIO)
/controller/vdd: C3.1, C4.1, C6.1, D30.1 (A), D31.1 (A), D32.1 (A), J8.6, R2.2, TP18.1, U1.12 (VDD), U1.24 (VDD), U1.32 (VDD)
/controller/vusb: C1.1, C7.1, R13.2, TP14.1, U1.23 (VBUS), U4.13 (IN)
unnamed: C2.1, C17.1, L2.2, R2.1, R5.1, TP17.1
unnamed: D30.2 (RK), R1.2
unnamed: F3.2, R14.1, TP10.1
unnamed: SW31.2 (B), U4.15 (SYSOFF)
unnamed: C2.2, R5.2, R9.1, U2.2 (FB)
unnamed: L2.1, U2.6 (SW)
unnamed: R7.1, U4.12 (ILIM)
unnamed: R8.1, U4.16 (ISET)
unnamed: R4.1, U4.1 (TS)
unnamed: TP1.1, U4.7 (~PGOOD)
USB0_N: R24.1, U3.6 (I/O1)
USB0_P: R25.1, U3.4 (I/O2)
USB_N: R24.2, U1.25 (USB_D-)
USB_P: R25.2, U1.26 (USB_D+)
cc1: J6.A5 (CC1), R20.1
cc2: J6.B5 (CC2), R23.1
col0: D52.2, D53.2, D54.2, D55.2, D58.2, D81.2, D82.2, D83.2, D84.2, D87.2, U1.17 (P0.06)
col0row0: D55.1, D84.1, S55.1, S84.1
col0row1: D54.1, D83.1, S54.1, S83.1
col0row2: D53.1, D82.1, S53.1, S82.1
col0row3: D52.1, D81.1, S52.1, S81.1
col0row4: D58.1, D87.1, S58.1, S87.1
col1: D48.2, D49.2, D50.2, D51.2, D57.2, D77.2, D78.2, D79.2, D80.2, D86.2, U1.16 (P0.27)
col1row0: D51.1, D80.1, S51.1, S80.1
col1row1: D50.1, D79.1, S50.1, S79.1
col1row2: D49.1, D78.1, S49.1, S78.1
col1row3: D48.1, D77.1, S48.1, S77.1
col1row4: D57.1, D86.1, S57.1, S86.1
col2: D43.2, D44.2, D45.2, D46.2, D56.2, D72.2, D73.2, D74.2, D75.2, D85.2, U1.15 (P0.26)
col2row0: D46.1, D75.1, S46.1, S75.1
col2row1: D45.1, D74.1, S45.1, S74.1
col2row2: D44.1, D73.1, S44.1, S73.1
col2row3: D43.1, D72.1, S43.1, S72.1
col2row4: D56.1, D85.1, S56.1, S85.1
col3: D38.2, D39.2, D40.2, D41.2, D47.2, D67.2, D68.2, D69.2, D70.2, D76.2, U1.14 (P0.04/AIN2)
col3row0: D41.1, D70.1, S41.1, S70.1
col3row1: D40.1, D69.1, S40.1, S69.1
col3row2: D39.1, D68.1, S39.1, S68.1
col3row3: D38.1, D67.1, S38.1, S67.1
col3row4: D47.1, D76.1, S47.1, S76.1
col4: D33.2, D34.2, D35.2, D36.2, D42.2, D62.2, D63.2, D64.2, D65.2, D71.2, U1.11 (AIN3)
col4row0: D36.1, D65.1, S36.1, S65.1
col4row1: D35.1, D64.1, S35.1, S64.1
col4row2: D34.1, D63.1, S34.1, S63.1
col4row3: D33.1, D62.1, S33.1, S62.1
col4row4: D42.1, D71.1, S42.1, S71.1
col5: D37.2, D59.2, D60.2, D61.2, D66.2, U1.10 (P0.30/AIN6)
col5row1: D61.1, S32.1, S61.1
col5row2: D60.1, S31.1, S60.1
col5row3: D59.1, S30.1, S59.1
col5row4: D37.1, D66.1, S37.1, S66.1
row0: S36.2, S41.2, S46.2, S51.2, S55.2, S65.2, S70.2, S75.2, S80.2, S84.2, U1.22 (P0.12)
row1: S32.2, S35.2, S40.2, S45.2, S50.2, S54.2, S61.2, S64.2, S69.2, S74.2, S79.2, S83.2, U1.21 (P1.09)
row2: S31.2, S34.2, S39.2, S44.2, S49.2, S53.2, S60.2, S63.2, S68.2, S73.2, S78.2, S82.2, U1.20 (P0.08)
row3: S30.2, S33.2, S38.2, S43.2, S48.2, S52.2, S59.2, S62.2, S67.2, S72.2, S77.2, S81.2, U1.19 (P0.09/NFC1)
row4: S37.2, S42.2, S47.2, S56.2, S57.2, S58.2, S66.2, S71.2, S76.2, S85.2, S86.2, S87.2, U1.18 (P0.10/NFC2)
sysgnd: C1.2, C3.2, C4.2, C5.2, C6.2, C7.2, C10.2, C16.2, C17.2, J1.1, J6.A1 (GND), J6.A12 (GND), J6.B1 (GND), J6.B12 (GND), J8.1, R4.2, R7.2, R8.2, R9.2, R20.2, R23.2, R30.2, SW31.1 (A), TP15.1, U1.1 (GND), U1.8 (P0.29/AIN5), U1.13 (GND), U1.27 (P0.13), U1.28 (P0.15), U1.29 (P0.17), U1.30 (P0.24), U1.35 (GND), U2.3 (AGND), U2.5 (PGND), U3.2 (GND), U4.4 (~CE), U4.6 (EN1), U4.8 (VSS), U4.17 (VSS)
usb1_n: J6.A7 (D-), J6.B7 (D-), U3.1 (I/O1)
usb1_p: J6.A6 (D+), J6.B6 (D+), U3.3 (I/O2)
vbus_fused: F4.2, R13.1, TP13.1, U3.5 (VBUS)
vbus_no_fuse: F4.1, J6.A4 (VBUS), J6.A9 (VBUS), J6.B4 (VBUS), J6.B9 (VBUS)
vsys: C16.1, TP16.1, U2.1 (EN), U2.7 (VIN), U4.10 (OUT), U4.11 (OUT)

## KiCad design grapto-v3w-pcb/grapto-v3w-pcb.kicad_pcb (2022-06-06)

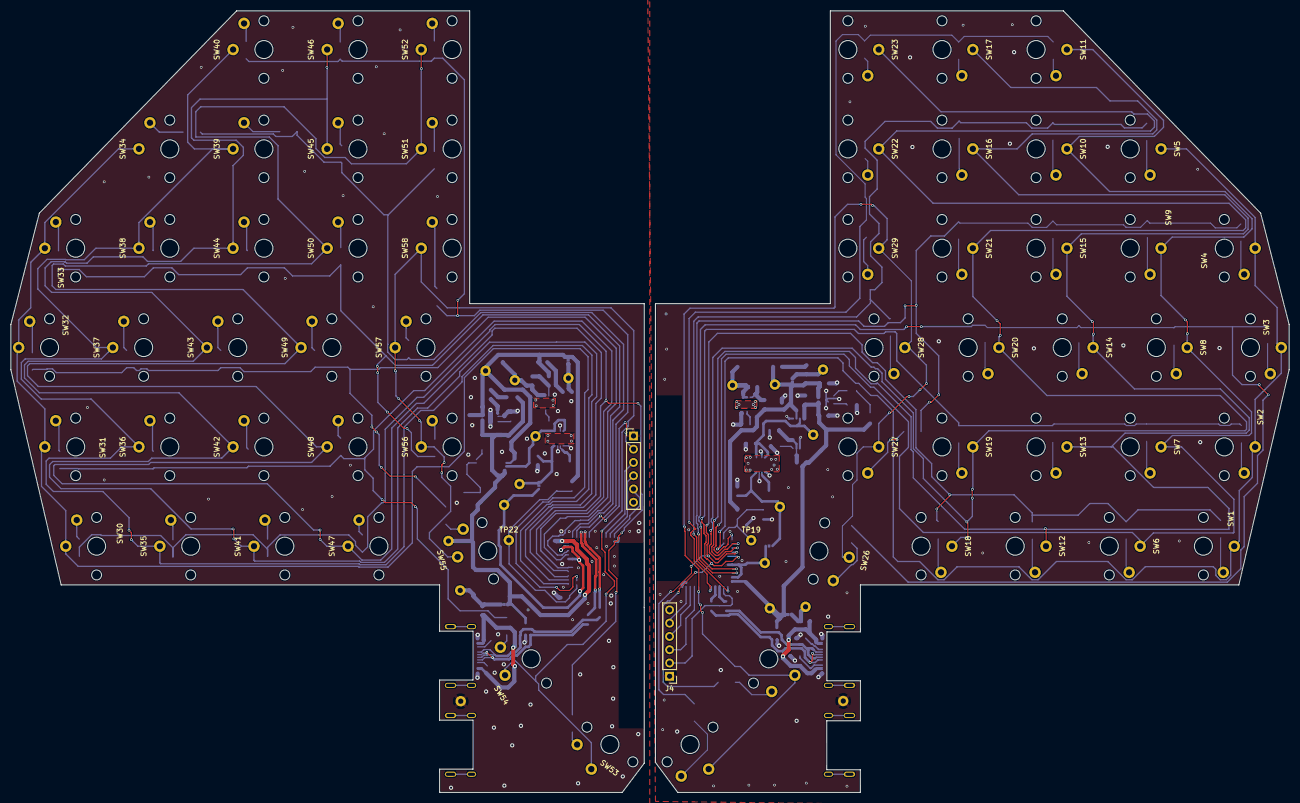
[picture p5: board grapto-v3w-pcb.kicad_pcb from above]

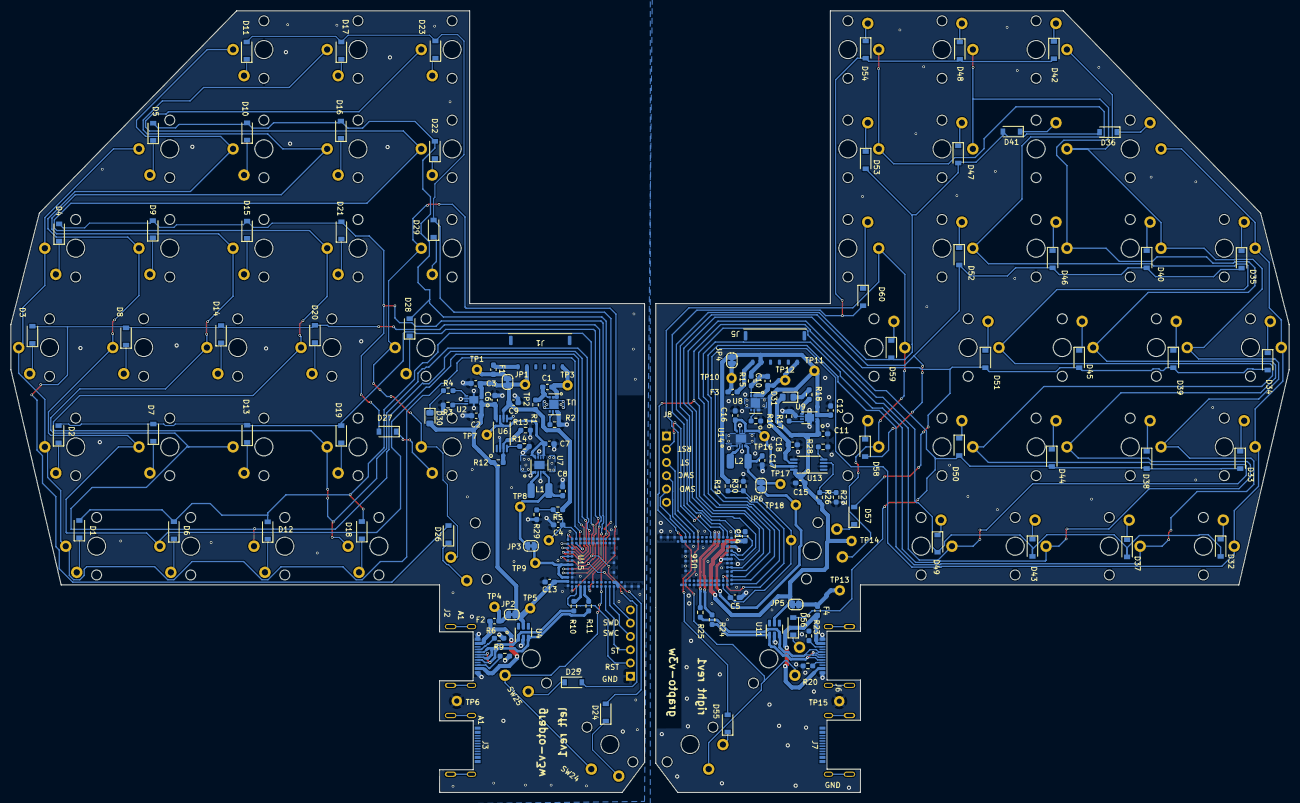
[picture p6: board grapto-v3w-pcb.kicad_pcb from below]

Board: 2 copper layers, 244.5 x 149.5 mm, 214 parts (152 on the bottom side), 140 nets.

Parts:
C1, C2, C3, C6, C7, C8, C9, C10, C11, C12, C13, C14, C15, C16, C17, C18: 22u; Fuse_0603_1608Metric_Pad1.05x0.95mm_HandSolder
C4, C5: .1u; C_0603_1608Metric_Pad1.08x0.95mm_HandSolder
D1, D2, D3, D4, D5, D6, D7, D8, D9, D10, D11, D12, D13, D14, D15, D16, D17, D18, D19, D20, D21, D22, D23, D24, D25, D26, D27, D28, D29, D32, D33, D34, D35, D36, D37, D38, D39, D40, D41, D42, D43, D44, D45, D46, D47, D48, D49, D50, D51, D52, D53, D54, D55, D56, D57, D58, D59, D60: D_SOD-123
D30, D31: LED; LED_0805_2012Metric_Pad1.15x1.40mm_HandSolder
F1, F2, F3, F4: Polyfuse; Fuse_0603_1608Metric_Pad1.05x0.95mm_HandSolder
J1, J5: Conn_01x06_Female; df65-6P-1.7V
J2, J3, J6, J7: USB_C_Receptacle_USB2.0; USB_C_Receptacle_molex_2169900001
J4, J8: Conn_01x06_Male; PinHeader_1x06_P2.54mm_Vertical
JP1, JP2, JP3, JP4, JP5, JP6: SolderJumper_2_Bridged; SolderJumper-2_P1.3mm_Bridged_RoundedPad1.0x1.5mm
L1, L2: 2.2; Bourns-SRP0415
R1, R14, R15, R28: 470; R_0603_1608Metric_Pad0.98x0.95mm_HandSolder
R2, R16: 2.7k; R_0603_1608Metric_Pad0.98x0.95mm_HandSolder
R3, R17: 4.7k; R_0603_1608Metric_Pad0.98x0.95mm_HandSolder
R4, R18: 150; R_0603_1608Metric_Pad0.98x0.95mm_HandSolder
R5, R19: 1M; R_0603_1608Metric_Pad0.98x0.95mm_HandSolder
R6, R9, R20, R23: 5.1k; R_0603_1608Metric_Pad0.98x0.95mm_HandSolder
R10, R11, R24, R25: 22; R_0603_1608Metric_Pad0.98x0.95mm_HandSolder
R12, R13, R26, R27: 4.7K; R_0603_1608Metric_Pad0.98x0.95mm_HandSolder
R29, R30: 2M; R_0603_1608Metric_Pad0.98x0.95mm_HandSolder
SW1, SW2, SW3, SW4, SW5, SW6, SW7, SW8, SW9, SW10, SW11, SW12, SW13, SW14, SW15, SW16, SW17, SW18, SW19, SW20, SW21, SW22, SW23, SW24, SW25, SW26, SW27, SW28, SW29, SW30, SW31, SW32, SW33, SW34, SW35, SW36, SW37, SW38, SW39, SW40, SW41, SW42, SW43, SW44, SW45, SW46, SW47, SW48, SW49, SW50, SW51, SW52, SW53, SW54, SW55, SW56, SW57, SW58: SW_Kailh_Choc_V1_1.00u
TP1, TP2, TP3, TP4, TP5, TP6, TP7, TP8, TP9, TP10, TP11, TP12, TP13, TP14, TP15, TP16, TP17, TP18: TestPoint; TestPoint_THTPad_D2.0mm_Drill1.0mm
TP19, TP22: TestPoint_THTPad_D2.0mm_Drill1.0mm
U1, U8: AP9211S-AL; U-DFN2030-6_type_c
U2, U9: MCP7383x-2xMC; DFN-8-1EP_3x2mm_P0.5mm_EP1.75x1.45mm
U4, U11: USBLC6-4SC6; SOT-23-6
U6, U13: TPS2110; TSSOP-8_4.4x3mm_P0.65mm
U7, U14: LM3676SD-3.3; WSON-8-1EP_3x3mm_P0.5mm_EP1.6x2.0mm
U15, U16: Laird_bl653

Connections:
/Left/3.3v: JP6.2 (B), TP18.1, U16.25 (VDD_HV), U16.31 (VDD), U16.32 (SIO_40/SPI_MOSI)
/Left/BatteryManagement/batt+: F3.1, J5.6
/Left/BatteryManagement/batt-: C10.2, J5.1, TP12.1, U8.1 (S1), U8.2 (VSS)
/Left/VBUS_NO_FUSE: F4.1, J6.A4 (VBUS), J6.A9 (VBUS), J6.B4 (VBUS), J6.B9 (VBUS)
/Left/chassi: J6.S1 (SHIELD), U8.7, U14.9 (EP)
/Left/col0: D32.2 (A), D37.2 (A), D43.2 (A), D49.2 (A), D55.2 (A), U16.37 (SIO_07/UART_CTS)
/Left/col1: D33.2 (A), D38.2 (A), D44.2 (A), D50.2 (A), D56.2 (A), U16.35 (SIO_06/UART_TX), U16.36 (SIO_26/I2C_SDA)
/Left/col2: D34.2 (A), D39.2 (A), D45.2 (A), D51.2 (A), D57.2 (A), U16.29 (SIO_08/UART_RX)
/Left/col3: D35.2 (A), D40.2 (A), D46.2 (A), D52.2 (A), D58.2 (A), U16.27 (SIO_11)
/Left/col4: D36.2 (A), D41.2 (A), D47.2 (A), D53.2 (A), D59.2 (A), U16.21 (SIO_16)
/Left/col5: D42.2 (A), D48.2 (A), D54.2 (A), D60.2 (A), U16.13 (SIO_20)
/Left/low_batt: C5.1, R19.2, R30.1, TP22.1, U16.45 (SIO_30/AIN6)
/Left/p+: C12.1, C18.1, J5.5, JP4.2 (B), R15.1, R19.1, TP11.1, U9.3 (VBAT), U9.4 (VBAT), U13.6 (IN2)
/Left/pmux_out: C16.1, TP16.1, U13.7 (OUT), U14.5 (EN), U14.8 (VIN)
/Left/reset: J8.2, U16.19 (nRESET/SIO_18)
/Left/row0: SW30.1, SW31.1, SW32.1, SW33.1, SW34.1, U16.46 (SIO_28/AIN4)
/Left/row1: SW35.1, SW36.1, SW37.1, SW38.1, SW39.1, SW40.1, U16.42 (SIO_01/XL1)
/Left/row2: SW41.1, SW42.1, SW43.1, SW44.1, SW45.1, SW46.1, U16.41 (SIO_01/XL2)
/Left/row3: SW47.1, SW48.1, SW49.1, SW50.1, SW51.1, SW52.1, U16.39 (SIO_05/UART_RTS/AIN3)
/Left/row4: SW53.1, SW54.1, SW55.1, SW56.1, SW57.1, SW58.1, U16.7 (SIO_32)
/Left/status: J8.3, U16.5 (SIO_35/nAutoRUN)
/Left/swdclk: J8.4, U16.3 (SWDCLK)
/Left/swdio: J8.5, U16.1 (SWDIO)
/Left/sysgnd: C5.2, C11.2, C12.2, C14.2, C15.2, C16.2, C17.2, C18.2, J6.A1 (GND), J6.A12 (GND), J6.B1 (GND), J6.B12 (GND), J8.1, R16.2, R17.2, R20.2, R23.2, R27.2, R28.2, R30.2, TP15.1, U8.6 (S2), U9.6 (VSS), U9.9 (EP), U11.2 (GND), U13.2 (D1), U13.5 (GND), U14.1 (PGND), U14.3 (MODE), U14.7 (SGND), U16.0 (GND), U16.2 (SDIO_36), U16.8 (SIO_25), U16.12 (SIO_21), U16.16 (SIO_17), U16.18 (SIO_15), U16.20 (SIO_13), U16.22 (SIO_14), U16.23 (GND), U16.26 (GND), U16.28 (SIO_12), U16.30 (SIO_41/SPI_CLK), U16.33 (GND), U16.34 (SIO_04/AIN2/SPI_MISO), U16.38 (SIO_27/I2C_SCL), U16.40 (GND), U16.43 (GND), U16.44 (SIO_31/AIN7), U16.47 (GND), U16.48 (SIO_29/AIN5), U16.49 (SIO_03/AIN1), U16.50 (SIO_02/AIN0), U16.51 (SIO_46), U16.52 (GND), U16.53 (SIO_47), U16.54 (SIO_44), U16.55 (GND), U16.56 (SIO_45), U16.57 (NFC2/SIO_10), U16.58 (GND), U16.59 (NFC1/SIO_09), U16.62 (SIO_42), U16.63 (SIO_38), U16.64 (SIO_39), U16.65 (GND), U16.66 (GND), U16.67 (GND), U16.68 (GND), U16.69 (GND), U16.70 (GND), U16.71 (GND)
/Left/usb1_n: J6.A7 (D-), J6.B7 (D-), R24.1, U11.1 (I/O1)
/Left/usb1_p: J6.A6 (D+), J6.B6 (D+), R25.1, U11.3 (I/O2)
/Left/vusb: C11.1, C14.1, C15.1, D31.2 (A), JP5.2 (B), R26.1, TP14.1, U9.1 (VDD), U9.2 (VDD), U11.5 (VBUS), U13.8 (IN1), U16.24 (VBUS)
/Right/3.3v: JP3.2 (B), TP9.1, U15.25 (VDD_HV), U15.31 (VDD), U15.32 (SIO_40/SPI_MOSI)
/Right/BatteryManagement/batt+: F1.1, J1.6
/Right/BatteryManagement/batt-: C1.2, J1.1, TP3.1, U1.1 (S1), U1.2 (VSS)
/Right/VBUS_NO_FUSE: F2.1, J2.A4 (VBUS), J2.A9 (VBUS), J2.B4 (VBUS), J2.B9 (VBUS)
/Right/chassi: J2.S1 (SHIELD), U1.7, U7.9 (EP)
/Right/col0: D1.2 (A), D6.2 (A), D12.2 (A), D18.2 (A), D24.2 (A), U15.37 (SIO_07/UART_CTS)
/Right/col1: D2.2 (A), D7.2 (A), D13.2 (A), D19.2 (A), D25.2 (A), U15.35 (SIO_06/UART_TX), U15.36 (SIO_26/I2C_SDA)
/Right/col2: D3.2 (A), D8.2 (A), D14.2 (A), D20.2 (A), D26.2 (A), U15.29 (SIO_08/UART_RX)
/Right/col3: D4.2 (A), D9.2 (A), D15.2 (A), D21.2 (A), D27.2 (A), U15.27 (SIO_11)
/Right/col4: D5.2 (A), D10.2 (A), D16.2 (A), D22.2 (A), D28.2 (A), U15.21 (SIO_16)
/Right/col5: D11.2 (A), D17.2 (A), D23.2 (A), D29.2 (A), U15.13 (SIO_20)
/Right/low_batt: C4.1, R5.2, R29.1, TP19.1, U15.45 (SIO_30/AIN6)
/Right/p+: C3.1, C9.1, J1.5, JP1.2 (B), R1.1, R5.1, TP2.1, U2.3 (VBAT), U2.4 (VBAT), U6.6 (IN2)
/Right/pmux_out: C7.1, TP7.1, U6.7 (OUT), U7.5 (EN), U7.8 (VIN)
/Right/reset: J4.2, U15.19 (nRESET/SIO_18)
/Right/row0: SW1.1, SW2.1, SW3.1, SW4.1, SW5.1, U15.46 (SIO_28/AIN4)
/Right/row1: SW6.1, SW7.1, SW8.1, SW9.1, SW10.1, SW11.1, U15.42 (SIO_01/XL1)
/Right/row2: SW12.1, SW13.1, SW14.1, SW15.1, SW16.1, SW17.1, U15.41 (SIO_01/XL2)
/Right/row3: SW18.1, SW19.1, SW20.1, SW21.1, SW22.1, SW23.1, U15.39 (SIO_05/UART_RTS/AIN3)
/Right/row4: SW24.1, SW25.1, SW26.1, SW27.1, SW28.1, SW29.1, U15.7 (SIO_32)
/Right/status: J4.3, U15.5 (SIO_35/nAutoRUN)
/Right/swdclk: J4.4, U15.3 (SWDCLK)
/Right/swdio: J4.5, U15.1 (SWDIO)
/Right/sysgnd: C2.2, C3.2, C4.2, C6.2, C7.2, C8.2, C9.2, C13.2, J2.A1 (GND), J2.A12 (GND), J2.B1 (GND), J2.B12 (GND), J4.1, R2.2, R3.2, R6.2, R9.2, R13.2, R14.2, R29.2, TP6.1, U1.6 (S2), U2.6 (VSS), U2.9 (EP), U4.2 (GND), U6.2 (D1), U6.5 (GND), U7.1 (PGND), U7.3 (MODE), U7.7 (SGND), U15.0 (GND), U15.2 (SDIO_36), U15.8 (SIO_25), U15.12 (SIO_21), U15.16 (SIO_17), U15.18 (SIO_15), U15.20 (SIO_13), U15.22 (SIO_14), U15.23 (GND), U15.26 (GND), U15.28 (SIO_12), U15.30 (SIO_41/SPI_CLK), U15.33 (GND), U15.34 (SIO_04/AIN2/SPI_MISO), U15.38 (SIO_27/I2C_SCL), U15.40 (GND), U15.43 (GND), U15.44 (SIO_31/AIN7), U15.47 (GND), U15.48 (SIO_29/AIN5), U15.49 (SIO_03/AIN1), U15.50 (SIO_02/AIN0), U15.51 (SIO_46), U15.52 (GND), U15.53 (SIO_47), U15.54 (SIO_44), U15.55 (GND), U15.56 (SIO_45), U15.57 (NFC2/SIO_10), U15.58 (GND), U15.59 (NFC1/SIO_09), U15.62 (SIO_42), U15.63 (SIO_38), U15.64 (SIO_39), U15.65 (GND), U15.66 (GND), U15.67 (GND), U15.68 (GND), U15.69 (GND), U15.70 (GND), U15.71 (GND)
/Right/usb1_n: J2.A7 (D-), J2.B7 (D-), R10.1, U4.1 (I/O1)
/Right/usb1_p: J2.A6 (D+), J2.B6 (D+), R11.1, U4.3 (I/O2)
/Right/vusb: C2.1, C6.1, C13.1, D30.2 (A), JP2.2 (B), R12.1, TP5.1, U2.1 (VDD), U2.2 (VDD), U4.5 (VBUS), U6.8 (IN1), U15.24 (VBUS)
unnamed: C1.1, R1.2, U1.3 (VDD)
unnamed: C8.1, JP3.1 (A), L1.2, TP8.1, U7.4 (FB)
unnamed: C10.1, R15.2, U8.3 (VDD)
unnamed: C17.1, JP6.1 (A), L2.2, TP17.1, U14.4 (FB)
unnamed: D1.1 (K), SW1.2
unnamed: D2.1 (K), SW2.2
unnamed: D3.1 (K), SW3.2
unnamed: D4.1 (K), SW4.2
unnamed: D5.1 (K), SW5.2
unnamed: D6.1 (K), SW6.2
unnamed: D7.1 (K), SW7.2
unnamed: D8.1 (K), SW8.2
unnamed: D9.1 (K), SW9.2
unnamed: D10.1 (K), SW10.2
unnamed: D11.1 (K), SW11.2
unnamed: D12.1 (K), SW12.2
unnamed: D13.1 (K), SW13.2
unnamed: D14.1 (K), SW14.2
unnamed: D15.1 (K), SW15.2
unnamed: D16.1 (K), SW16.2
unnamed: D17.1 (K), SW17.2
unnamed: D18.1 (K), SW18.2
unnamed: D19.1 (K), SW19.2
unnamed: D20.1 (K), SW20.2
unnamed: D21.1 (K), SW21.2
unnamed: D22.1 (K), SW22.2
unnamed: D23.1 (K), SW23.2
unnamed: D24.1 (K), SW24.2
unnamed: D25.1 (K), SW25.2
unnamed: D26.1 (K), SW26.2
unnamed: D27.1 (K), SW27.2
unnamed: D28.1 (K), SW28.2
unnamed: D29.1 (K), SW29.2
unnamed: D30.1 (K), R4.1
unnamed: D31.1 (K), R18.1
unnamed: D32.1 (K), SW30.2
unnamed: D33.1 (K), SW31.2
unnamed: D34.1 (K), SW32.2
unnamed: D35.1 (K), SW33.2
unnamed: D36.1 (K), SW34.2
unnamed: D37.1 (K), SW35.2
unnamed: D38.1 (K), SW36.2
unnamed: D39.1 (K), SW37.2
unnamed: D40.1 (K), SW38.2
unnamed: D41.1 (K), SW39.2
unnamed: D42.1 (K), SW40.2
unnamed: D43.1 (K), SW41.2
unnamed: D44.1 (K), SW42.2
unnamed: D45.1 (K), SW43.2
unnamed: D46.1 (K), SW44.2
unnamed: D47.1 (K), SW45.2
unnamed: D48.1 (K), SW46.2
unnamed: D49.1 (K), SW47.2
unnamed: D50.1 (K), SW48.2
unnamed: D51.1 (K), SW49.2
unnamed: D52.1 (K), SW50.2
unnamed: D53.1 (K), SW51.2
unnamed: D54.1 (K), SW52.2
unnamed: D55.1 (K), SW53.2
unnamed: D56.1 (K), SW54.2
unnamed: D57.1 (K), SW55.2
unnamed: D58.1 (K), SW56.2
unnamed: D59.1 (K), SW57.2
unnamed: D60.1 (K), SW58.2
unnamed: F1.2, JP1.1 (A), TP1.1
unnamed: F2.2, JP2.1 (A), TP4.1
unnamed: F3.2, JP4.1 (A), TP10.1
unnamed: F4.2, JP5.1 (A), TP13.1
unnamed: J2.A5 (CC1), R6.1
unnamed: J2.B5 (CC2), R9.1
unnamed: J6.A5 (CC1), R20.1
unnamed: J6.B5 (CC2), R23.1
unnamed: L1.1, U7.2 (SW)
unnamed: L2.1, U14.2 (SW)
unnamed: R2.1, U1.5 (VM)
unnamed: R3.1, U2.8 (PROG)
unnamed: R4.2, U2.5 (STAT)
unnamed: R12.2, R13.1, U6.3 (VSNS)
unnamed: R14.1, U6.4 (ILIM)
unnamed: R16.1, U8.5 (VM)
unnamed: R17.1, U9.8 (PROG)
unnamed: R18.2, U9.5 (STAT)
unnamed: R26.2, R27.1, U13.3 (VSNS)
unnamed: R28.1, U13.4 (ILIM)
USB_N: R10.2, R24.2, U15.17 (D-), U16.17 (D-)
USB_P: R11.2, R25.2, U15.15 (D+), U16.15 (D+)

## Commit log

2022-03-06 Started with case.
    [grapto-v3w.FCStd]
2022-03-06 Added snaps to bottom
    [grapto-v3w.FCStd]
2022-03-06 Added snaps
    [grapto-v3w.FCStd]
2022-03-19 Found promising snap design.
    [grapto-v3w.FCStd]
2022-03-19 improved snaps.
    [grapto-v3w.FCStd]
2022-04-03 Updated schematic.
    [grapto-v3w.FCStd]
2022-04-04 Added schematic.
    [grapto-v3w-pcb.kicad_pcb, grapto-v3w-pcb.kicad_sch]
2022-04-09 Before removing pmux.
    [grapto-v3w-pcb.kicad_sch]
2022-04-10 minor changes.
    [grapto-v3w-pcb.kicad_sch]
2022-04-10 First draft of controller pcb
    [grapto-v3w-pcb.kicad_sch]
2022-04-10 Began experimenting with modules
    [Matrix.kicad_sch, controller.kicad_sch, grapto-v3w-pcb.kicad_sch]
2022-04-10 Think i got modules working.
    [Matrix.kicad_sch, controller.kicad_sch, grapto-v3w-pcb.kicad_sch]
2022-04-13 Added keymatrix.
    [Matrix.kicad_sch, controller.kicad_sch, grapto-v3w-pcb.kicad_sch]
2022-04-14 schematic soon finished.
    [Matrix.kicad_sch, controller.kicad_sch, grapto-v3w-pcb.kicad_pcb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]
2022-04-18 Footprints done.
    [Matrix.kicad_sch, battery_management.kicad_sch, controller.kicad_sch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]
2022-04-19 Fixed 3d model paths for pcb.
    [Matrix.kicad_sch, battery_management.kicad_sch, controller.kicad_sch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]
2022-04-23 Began case rework.
    [Matrix.kicad_sch, controller.kicad_sch, grapto-v3w-pcb-model.FCStd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]
2022-04-23 flipping usbs
    [controller.kicad_sch, grapto-v3w-pcb-model.FCStd, grapto-v3w-pcb.kicad_pcb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]
2022-04-23 Fixing pcb coordinates.
    [grapto-v3w-pcb-model.FCStd, grapto-v3w-pcb.kicad_pcb]
2022-04-23 Think freecad and kicad models are synced now.
    [grapto-v3w-pcb-model.FCStd, grapto-v3w-pcb.kicad_pcb]
2022-04-23 Reworking case.
    [grapto-v3w-pcb-model.FCStd]
2022-04-23 case rework done.
    [grapto-v3w-pcb-model.FCStd]
2022-04-24 Ready for layout.
    [grapto-v3w-pcb-model.FCStd, grapto-v3w-pcb.kicad_pcb]
2022-04-24 Began layout
    [grapto-v3w-pcb.kicad_pcb]
2022-04-24 layout and snaps
    [grapto-v3w-pcb-model.FCStd, grapto-v3w-pcb.kicad_pcb]
2022-05-06 Added snap supports.
    [battery_management.kicad_sch, controller.kicad_sch, grapto-v3w-pcb-model.FCStd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]
2022-05-11 More layout. esd chip problems.
    [battery_management.kicad_sch, controller.kicad_sch, grapto-v3w-pcb-model.FCStd]
2022-05-12 all nets connected.
    [controller.kicad_sch]
2022-05-14 need to fix silkscreens.
2022-05-15 pcb rev1
2022-05-18 Began changing mcu module.
    [controller.kicad_sch, grapto-v3w-pcb-model.FCStd, grapto-v3w-pcb.kicad_sch]
2022-05-31 Removing fuel gauge. Going for 2-layer board.
    [battery_management.kicad_sch, controller.kicad_sch, grapto-v3w-pcb.kicad_sch]
2022-06-04 Adjusting schematic to improve layout.
    [battery_management.kicad_sch, controller.kicad_sch, grapto-v3w-pcb.kicad_sch]
2022-06-04 Left half 2 layer initial layout.
    [controller.kicad_sch, grapto-v3w-pcb.kicad_pcb]
2022-06-05 Initial 2 layer layout right.
    [controller.kicad_sch, grapto-v3w-pcb.kicad_pcb]
2022-06-05 Before drc fixes.
    [grapto-v3w-pcb.kicad_pcb]
2022-06-06 2-layer layout ready to order.
    [battery_management.kicad_sch, controller.kicad_sch, grapto-v3w-pcb.kicad_pcb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]
2022-10-22 Restart case.
    [grapto-v3w-pcb-model.FCStd]
2022-12-28 Started with new ergogen based pcb.
    [Matrix.kicad_sch, battery_management.kicad_sch, controller.kicad_sch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]
2023-02-18 not sure what this is
    [grapto-v3w-pcb-model.FCStd]
2023-02-19 Synchronize ergogen output with freecad.
    [grapto-v3w-pcb-model.FCStd, grapto-v3w-right.kicad_pcb]
2023-02-19 minor case fix
    [grapto-v3w-pcb-model.FCStd]
2023-02-20 Update case to fit how swaps.
    [grapto-v3w-pcb-model.FCStd]
2023-02-20 small case tweak.
    [grapto-v3w-pcb-model.FCStd]
2023-02-20 update generated pcbs
    [controller.kicad_sch, grapto-v3w-left.kicad_pcb, grapto-v3w-left.kicad_sch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]
2023-02-25 Redesign pcb with new mcu and charger
    [battery_management.kicad_sch, controller.kicad_sch, grapto-v3w-left.kicad_sch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]
2023-02-26 schematic rewrite draft done.
    [battery_management.kicad_sch, controller.kicad_sch, grapto-v3w-left.kicad_pcb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]
2023-03-04 Schematic work.
    [battery_management.kicad_sch, controller.kicad_sch, grapto-v3w-left.kicad_sch]
2023-03-05 Schematic fine-tuning.
    [battery_management.kicad_sch, controller.kicad_sch, grapto-v3w-left.kicad_sch]
2023-03-07 Added footprints.
    [battery_management.kicad_sch, controller.kicad_sch, grapto-v3w-left.kicad_pcb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]
2023-03-08 before adding hotswaps
    [battery_management.kicad_sch, controller.kicad_sch, grapto-v3w-left.kicad_pcb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]
2023-03-12 left half pcb draft.
    [BOM-grapto-v3w-left.csv, battery_management.kicad_sch, controller.kicad_sch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]
2023-03-14 left pcb fix drc.
    [grapto-v3w-left.kicad_pcb]
2023-03-16 Right pcb almost finished.
    [battery_management.kicad_sch, controller.kicad_sch, grapto-v3w-right.kicad_pcb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]
2023-03-19 Production files sent to jlcpcb.
    [BOM-grapto-v3w-right.csv, battery_management.kicad_sch, controller.kicad_sch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]
2023-03-21 Case leds and usb cable cutout.
